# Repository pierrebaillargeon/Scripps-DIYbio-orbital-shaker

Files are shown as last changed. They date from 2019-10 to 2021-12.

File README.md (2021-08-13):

# Scripps-DIYbio-orbital-shaker
 Electronic circuitboard designed for the DIYbio orbital shaker project (https://www.thingiverse.com/thing:2633507).
 
 An assembly guide for this project can be found here: https://scrippsresearch.dozuki.com/Guide/How+to+assemble+a+DIYbio+orbital+shaker/1
 
 All files were generated using KiCad 5. Gerber files necessary to order PCBs can be found in the GERBER-v1.1 subdirectory.
 
  Close up photo of DIYbio orbital shaker PCB v1.1.
 
  Three DIYbio orbital shaker v1.1 PCBs prior to assembly.
 
  Three DIYbio orbital shaker v1.1 PCBs post assembly.
 
 Three DIYbio orbital shaker v1.1 PCBs with all peripheral devices connected.
 
  Photo illustrating DIYbio orbital shaker with custom PCB versus prior version made with protoboard.

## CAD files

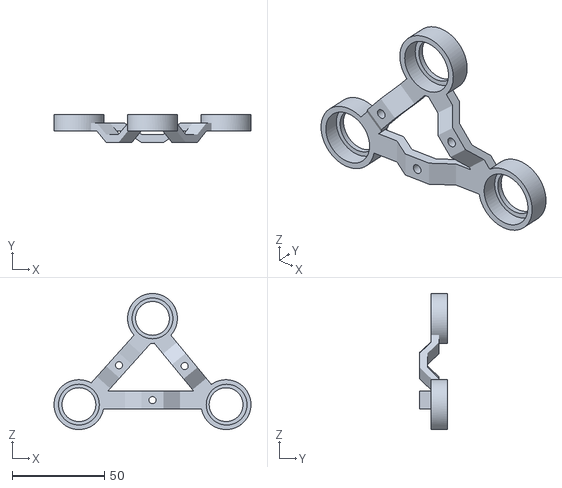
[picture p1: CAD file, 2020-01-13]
CAD models/STL/DIYbio orbital shaker - bearing linkage.stl
106.7 x 15.1 x 73.7

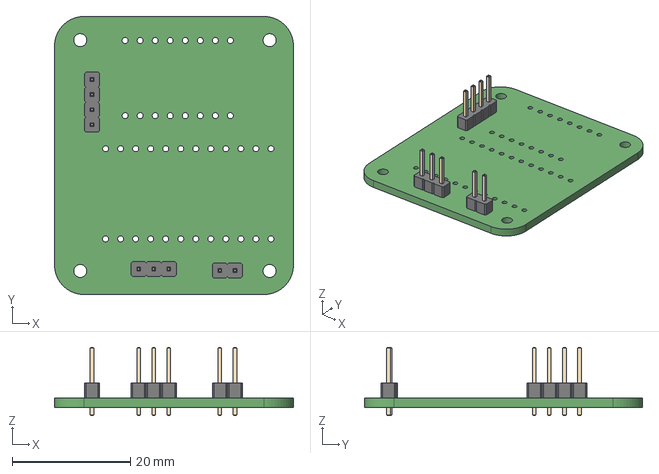
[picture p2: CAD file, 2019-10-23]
Electronics/orbital shaker.step
40.4 x 47.0 x 11.5 mm

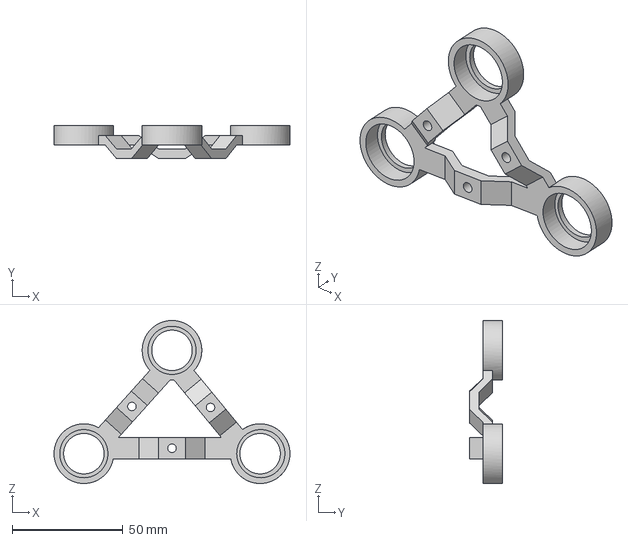
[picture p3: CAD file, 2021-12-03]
CAD models/STEP/bearingLinkage.step
106.7 x 15.1 x 73.7 mm

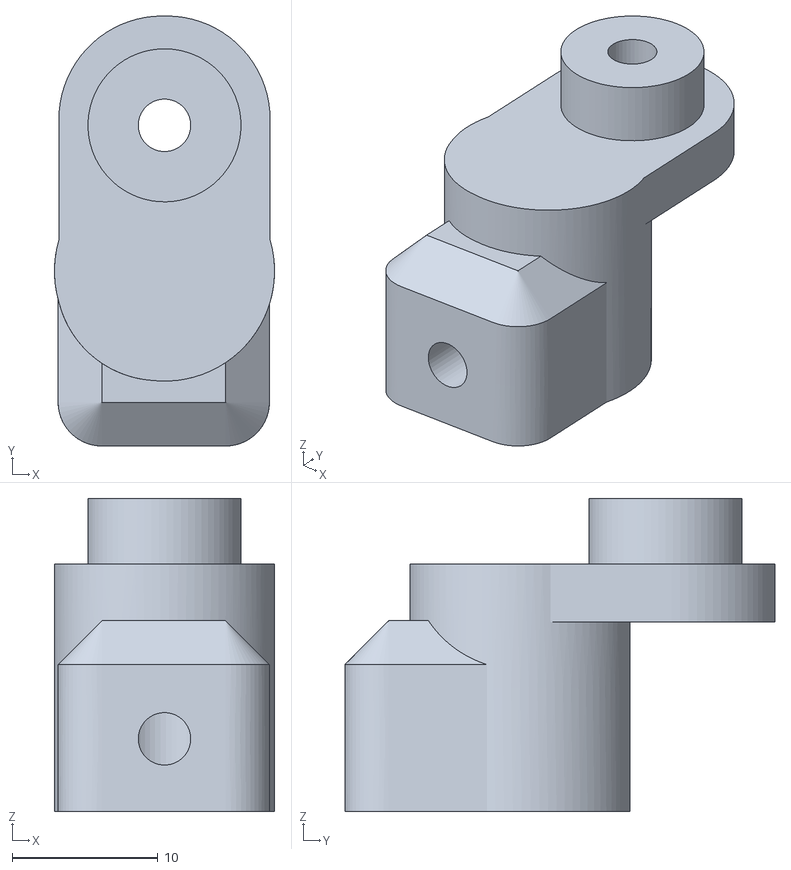
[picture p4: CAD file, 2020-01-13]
CAD models/STL/DIYbio orbital shaker - motor coupler.stl
15.1 x 29.5 x 21.5

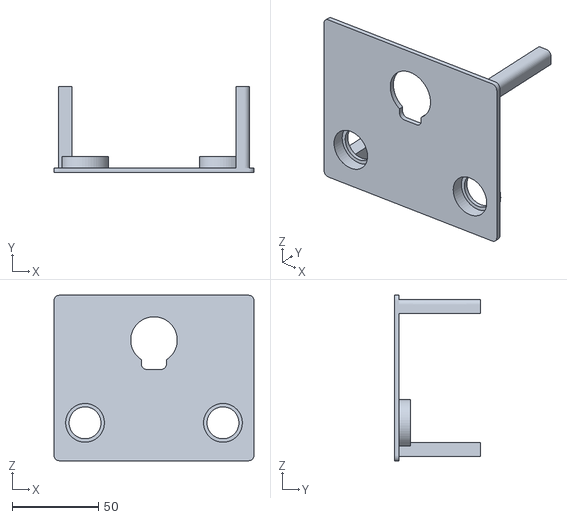
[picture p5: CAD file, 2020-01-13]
CAD models/STL/DIYbio orbital shaker - top case.stl
116.0 x 49.8 x 96.0

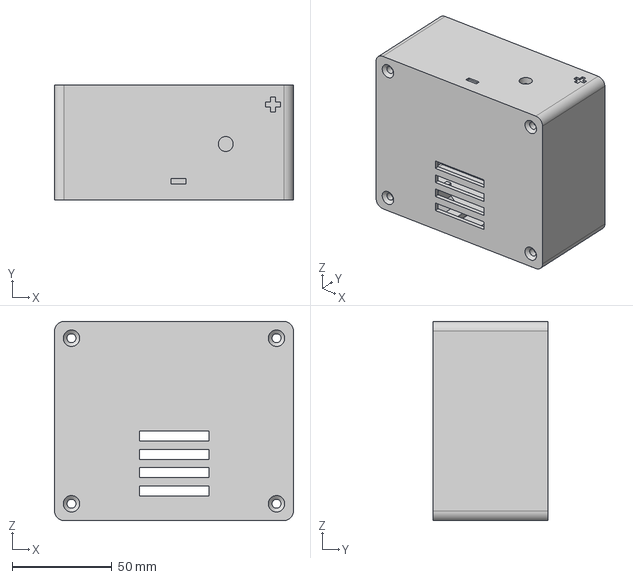
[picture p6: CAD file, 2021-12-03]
CAD models/STEP/shakerEnclosure.step
120.0 x 57.5 x 100.0 mm

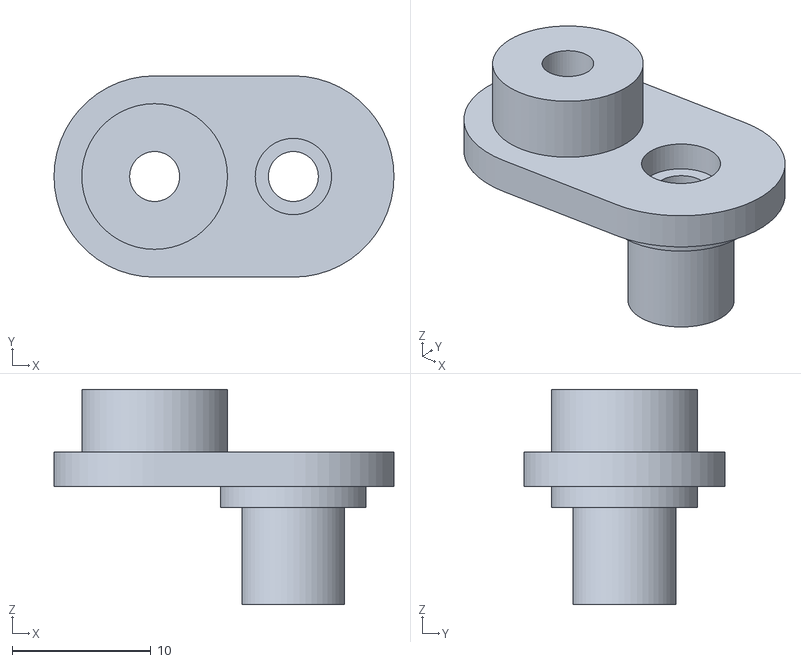
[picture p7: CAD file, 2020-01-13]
CAD models/STL/DIYBio orbital shaker - non-motor couplers.stl
24.5 x 14.5 x 15.5

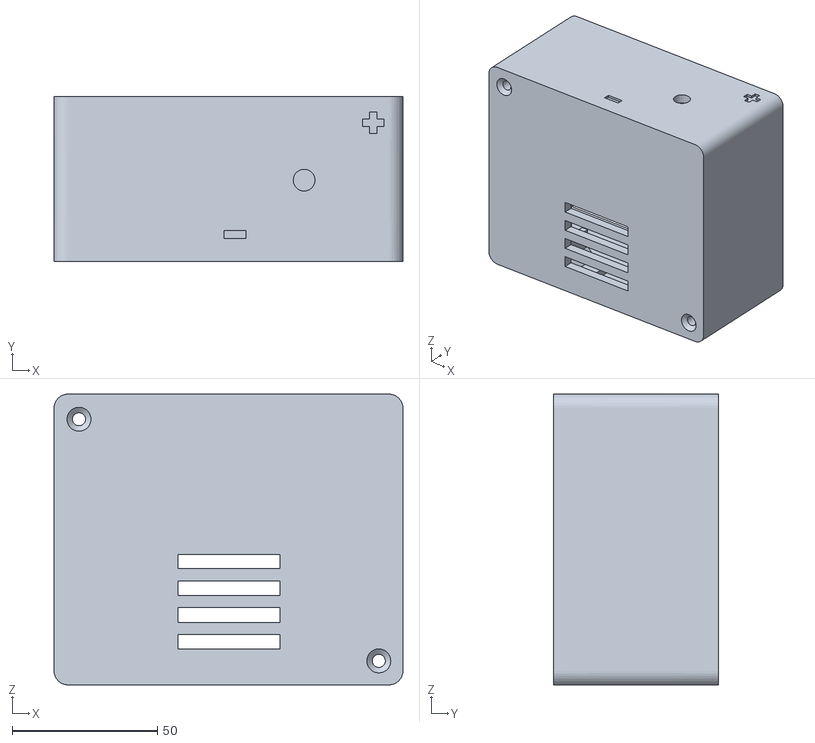
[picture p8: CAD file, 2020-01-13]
CAD models/STL/DIYbio orbital shaker bottom case.stl
120.0 x 56.8 x 100.0

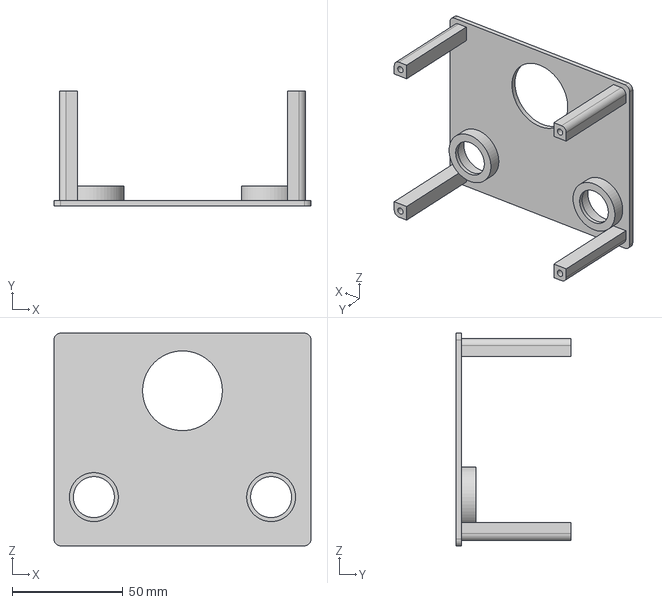
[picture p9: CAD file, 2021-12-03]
CAD models/STEP/shakerTop.step
116.0 x 51.8 x 96.0 mm

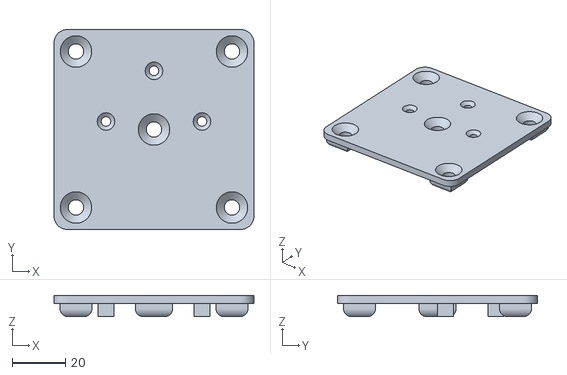
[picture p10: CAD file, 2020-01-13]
CAD models/STL/DIYbio orbital shaker - flask platform.stl
75.0 x 75.0 x 8.00

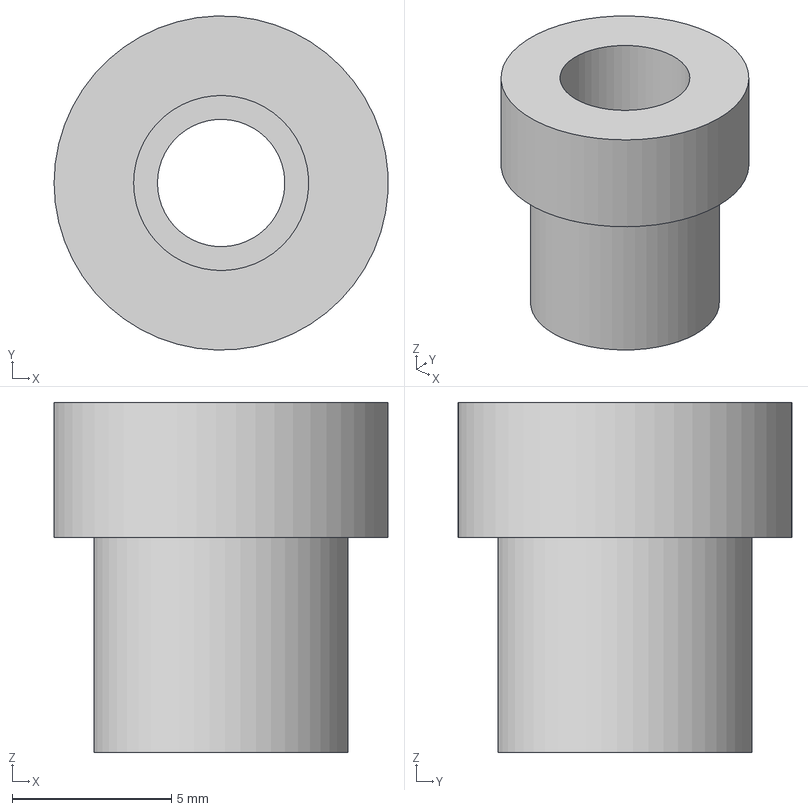
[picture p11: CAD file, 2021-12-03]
CAD models/STEP/screwAdapter.step
10.5 x 10.5 x 11.0 mm

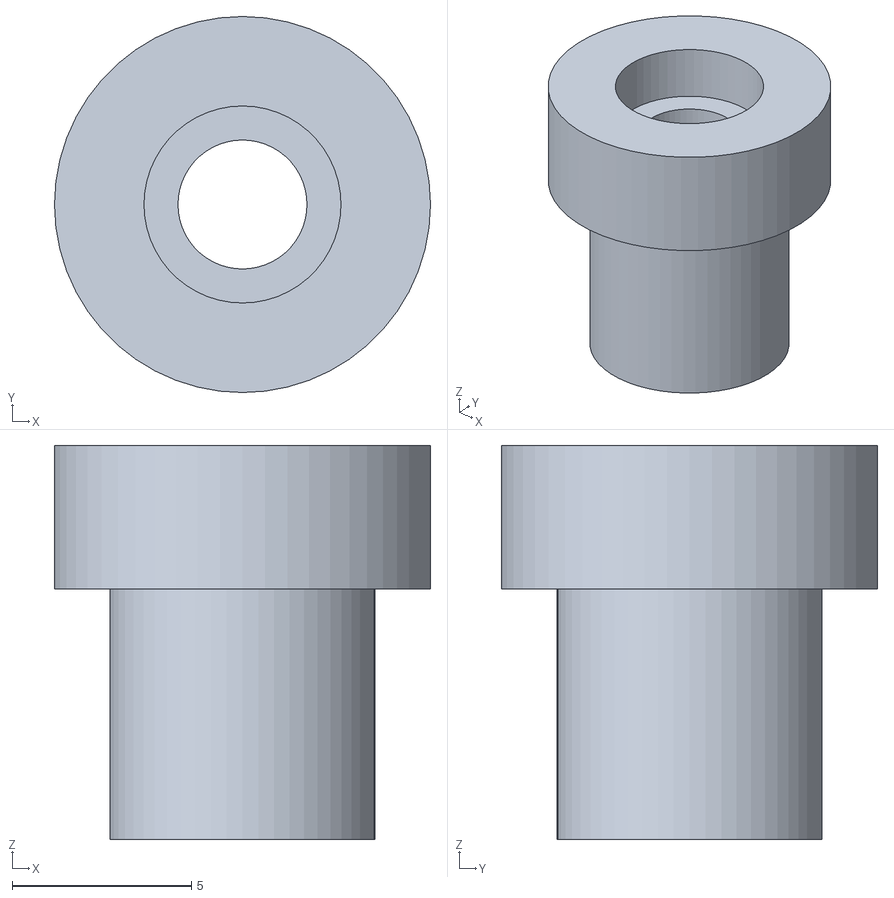
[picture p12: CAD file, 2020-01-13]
CAD models/STL/DIYbio orbital shaker - bearing screw adapters.stl
10.5 x 10.5 x 11.0

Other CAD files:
CAD models/STEP/coupler.step
CAD models/STEP/MotorCoupler.step
CAD models/STEP/modifiedShakerPlatform.step
CAD models/Fusion 360/bearingLinkage.f3z
CAD models/Fusion 360/bearingScrewAdapter.f3d
CAD models/Fusion 360/enclosure.f3z
CAD models/Fusion 360/modifiedShakerPlatform.f3d
CAD models/Fusion 360/motorCoupler.f3d
CAD models/Fusion 360/shakerTop.f3z

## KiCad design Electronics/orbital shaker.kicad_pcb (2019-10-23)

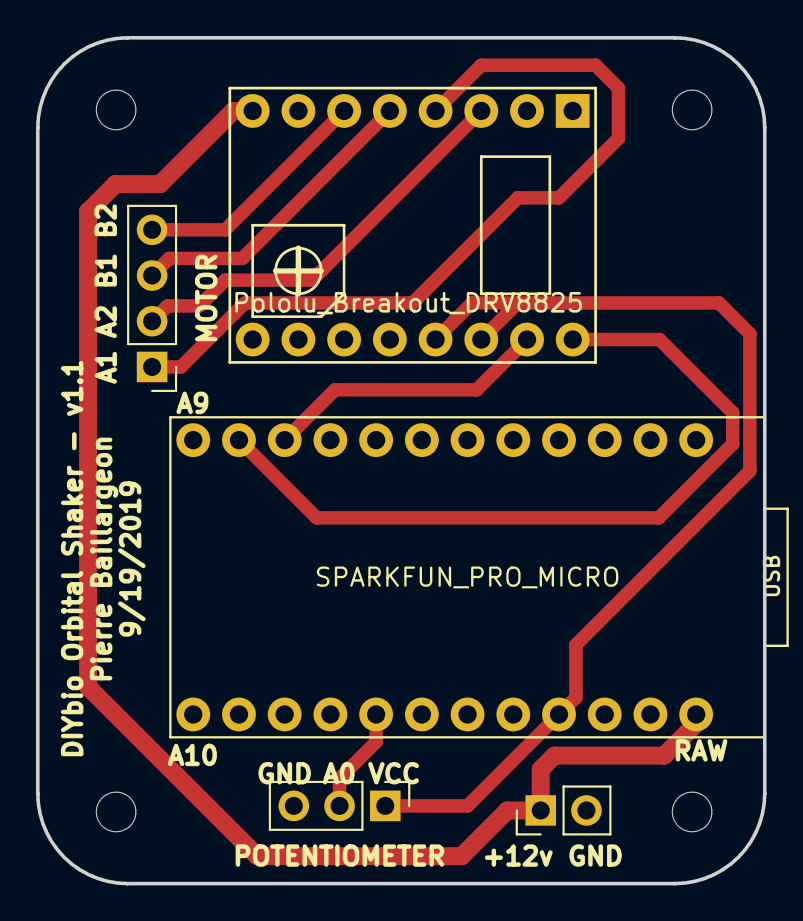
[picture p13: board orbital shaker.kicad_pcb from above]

Board: 2 copper layers, 40.4 x 47.0 mm, 5 parts (0 on the bottom side), 10 nets.

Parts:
A1: Pololu_Breakout_DRV8825; POLOLU-DRV8825
B1: SPARKFUN_PRO_MICRO
J1: Conn_01x02_Female; Pin_Header_Straight_1x02_Pitch2.54mm
J2: Conn_01x04_Female; Pin_Header_Straight_1x04_Pitch2.54mm
J3: Conn_01x03_Female; Pin_Header_Straight_1x03_Pitch2.54mm

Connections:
+12V: A1.8, B1.24, J1.1
GND: A1.1, A1.7, B1.3, B1.4, B1.23, J1.2, J3.3
unnamed: A1.3, J2.2
unnamed: A1.4, J2.1
unnamed: A1.5, J2.3
unnamed: A1.6, J2.4
unnamed: A1.13, A1.14, B1.21, J3.1
unnamed: A1.15, B1.10
unnamed: A1.16, B1.11
unnamed: B1.17, J3.2

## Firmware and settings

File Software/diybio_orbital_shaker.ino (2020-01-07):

// Simple Stepper Motor Control
//
// by Achim pieters, www.studiopieters.nl
// updated by Pierre Baillargeon to reflect usage for DIYbio orbital shaker
//

// Defines pins numbers
const int stepPin = 7;
const int dirPin = 8;

int potentiometerDelayValue,mappedPotentiometerValue; // Defines variables

void setup() {
  // Sets the two pins as Outputs
  pinMode(stepPin,OUTPUT);
  pinMode(dirPin,OUTPUT);
  Serial.begin(9600);
  digitalWrite(dirPin,HIGH); //Enables the motor to move in a particular direction
}

void loop() {
  potentiometerDelayValue = potentiometerRead(); // Gets custom delay values from the custom speedUp function
  // Makes pules with custom delay, depending on the Potentiometer, from which the speed of the motor depends
  digitalWrite(stepPin, HIGH);
  delayMicroseconds(potentiometerDelayValue);
  digitalWrite(stepPin, LOW);
  delayMicroseconds(potentiometerDelayValue);
}

// Function for reading the Potentiometer
int potentiometerRead() {
  int rawPotentiometerValue = analogRead(A0); // Reads the potentiometer
  int mappedPotentiometerValue = map(rawPotentiometerValue, 0, 1023, 550,4000); // Convrests the read values of the potentiometer from 0 to 1023 into desireded delay values (300 to 4000)
  Serial.println(mappedPotentiometerValue);
  return mappedPotentiometerValue;
}

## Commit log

2019-10-23 Added photos of PCB
    Adding photos of PCB before and after assembly in DIYbio orbital shaker.
2019-10-23 Added photos of PCB in various stage of assembly.
2020-01-07 Adding orbital shaker Arduino firmware to repository
2020-01-07 Added link to assembly guide
2020-01-13 Added 3D model files for v1.1
    Includes STL files for 3D printing and .f3z/.f3d files for editing in Fusion 360.
    [DIYBio orbital shaker - non-motor couplers.stl, DIYbio orbital shaker - bearing linkage.stl, DIYbio orbital shaker - bearing screw adapters.stl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]
2021-08-13 Reorganized directory structure
    [DIYBio orbital shaker - non-motor couplers.stl, DIYbio orbital shaker - bearing linkage.stl, DIYbio orbital shaker - bearing screw adapters.stl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]
2021-12-03 Reorganized CAD folder and added STEP files
    Exported STEP files for non-Fusion 360 users and organized all CAD files into subfolders.
    [DIYBio orbital shaker - non-motor couplers.stl, DIYbio orbital shaker - bearing linkage.stl, DIYbio orbital shaker - bearing screw adapters.stl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]
2021-12-03 CAD folder file name cleanup + added missing components
    [bearingLinkage.f3z, bearingLinkage.step, bearingScrewAdapter.f3d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]
2021-12-08 Added front PCB copper layer export in SVG
    Added front copper layer design in SVG format for anyone who would like to recreate using a DIY etching technique.
